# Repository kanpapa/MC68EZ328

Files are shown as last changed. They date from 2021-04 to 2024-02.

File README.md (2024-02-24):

# MC68EZ328 DragonOne SBC

We are designing the MC68EZ328 DragonOne SBC with KiCad.

Based on DragonOne V1.0 (C) Khaled Hassounah  
http://www.mediumware.net/DragonOne/DragonOne.htm  

## Spec

* CPU: MC68EZ328 DragonBall-EZ
* Flash Memory: Am29LV033C 32 Megabit (4M x 8-Bit) x 2
* DRAM: MT4LC4M16R6 64 Megabit (4M x 16-bit)
* RTC: DS1306

## Repository Contents

* /b/
  * All b-record for programming and testing the MC68EZ328 DragonOne.
* /bbug/
  * BBUG: a bootstrap mode debugger. Implementation of BBUG using python3 and pyserial.
* /d/
  * This is the data to execute a series of commands in 68k-Monitor.  
* /Hardware/
  * PDF files of schematics and BOMs
* /KiCad/
  * PCB design data and Gerber data for [KiCad](https://www.kicad.org/).
* /Pictues/
  * some pictures
* /src
  * All Source Code for Flash Programming and test programming. The assembler uses [EASy68K](http://www.easy68k.com/).

## How to install uClinux for the DragonOne SBC

[How to install uClinux](/uClinux-build2flash_en.md)  

See below for the uClinux source code and tools for the MC68EZ328 DragonOne SBC.  
https://github.com/kanpapa/uClinux-dist-20020220  
https://github.com/kanpapa/m68k-elf-tools  

## Blog

You can also refer to my blog. (in Japanese)    
https://kanpapa.com/today/electronics/microcomputer/mc68ez328/

## Pictures

MC68EZ328 CPU  
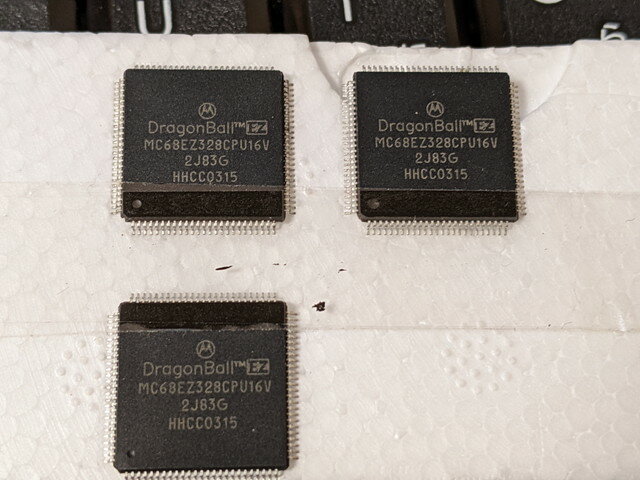
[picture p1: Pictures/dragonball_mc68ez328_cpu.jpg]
MC68EZ328 CPU


CPU board Rev. 0.3 PCB image  
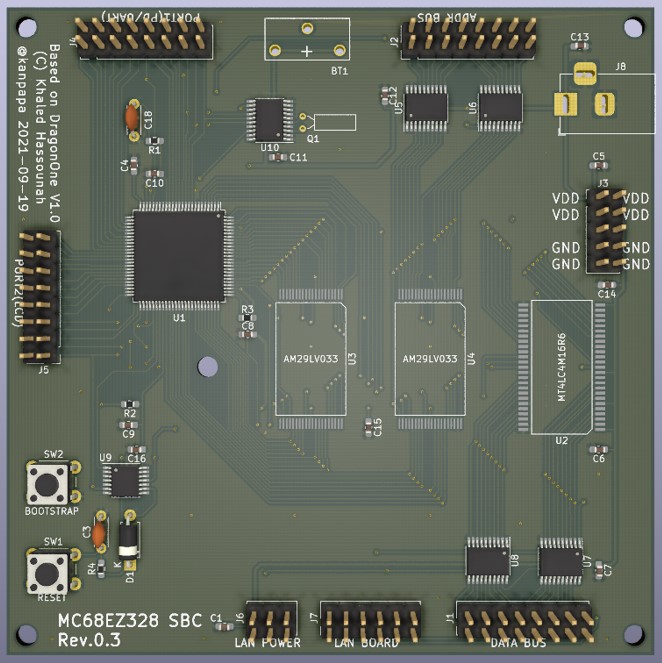
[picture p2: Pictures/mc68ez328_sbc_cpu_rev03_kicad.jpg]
CPU PCB image by KiCad


LAN board Rev. 0.2 PCB image  
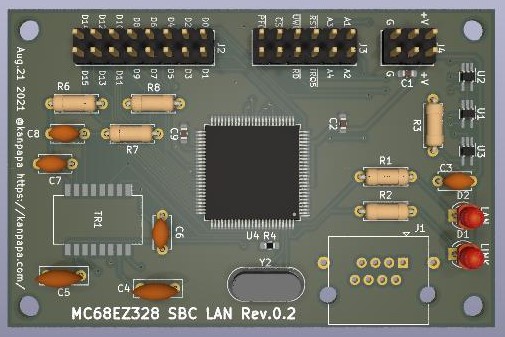
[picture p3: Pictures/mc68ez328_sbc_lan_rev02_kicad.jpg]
LAN PCB image by KiCad


Running uClinux  
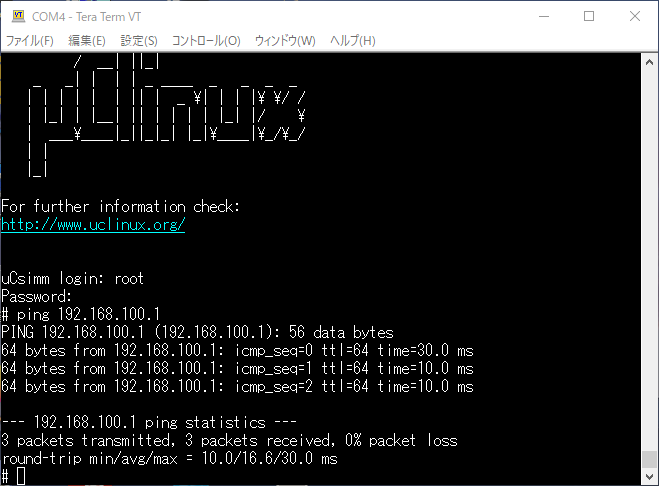
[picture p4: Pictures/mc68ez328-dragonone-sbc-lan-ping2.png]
Running uClinux


Running Network!  
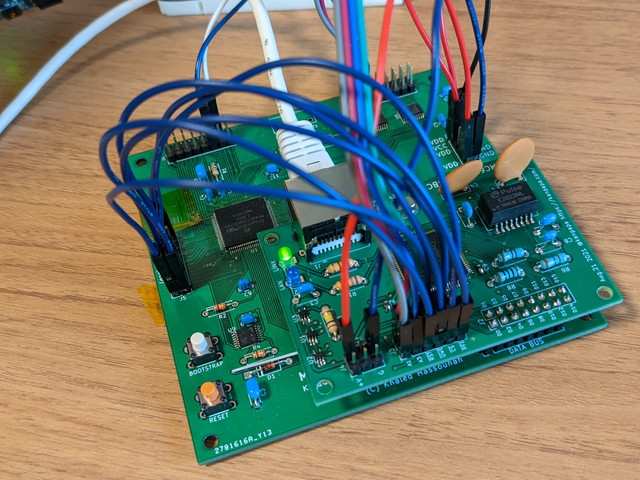
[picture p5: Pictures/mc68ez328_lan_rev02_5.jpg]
Running Network


## License Information

This code is public domain under the BSD-3-Clause License.  
Copyright (c) 2021, Kazuhiro Ouchi  
All rights reserved.  

References to any products, programs or services do not imply that they will be available in all countries in which their respective owner operates.

Company, product, or services names may be trademarks or services marks of others.

All libraries used in this code are copyright their respective authors.

68k-Monitor Copyright (c) 2015, Hayden Kroepfl

The DragonOne Microcomputer hardware design Copyright (C) Khaled Hassounah

Many thanks to the original authors for making their designs and code avaialble as open source.

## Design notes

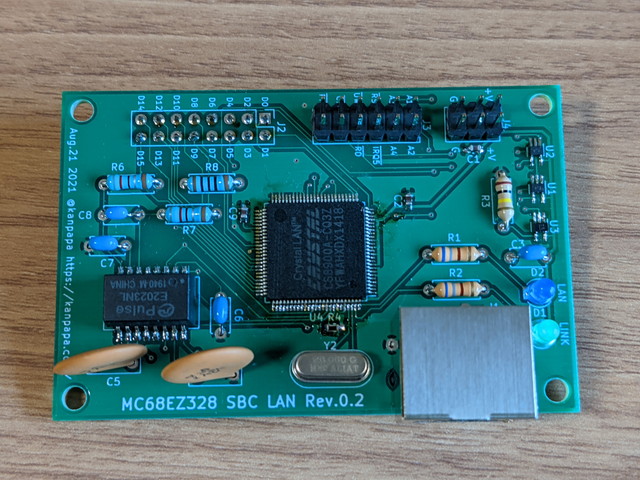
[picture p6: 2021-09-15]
Pictures/mc68ez328_lan_rev02_3.jpg

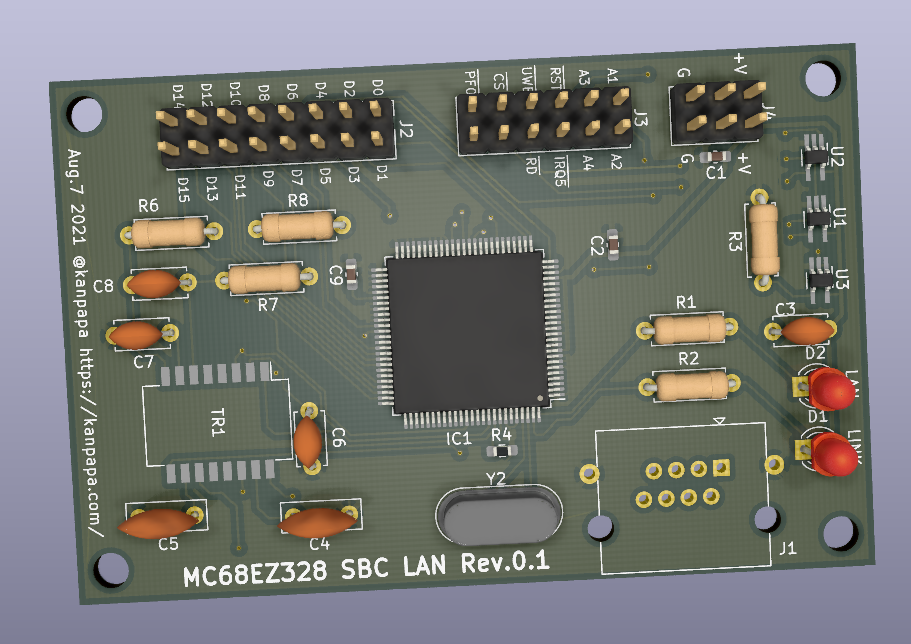
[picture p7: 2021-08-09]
Pictures/mc68ez328_sbc_lan_rev01_kicad.png

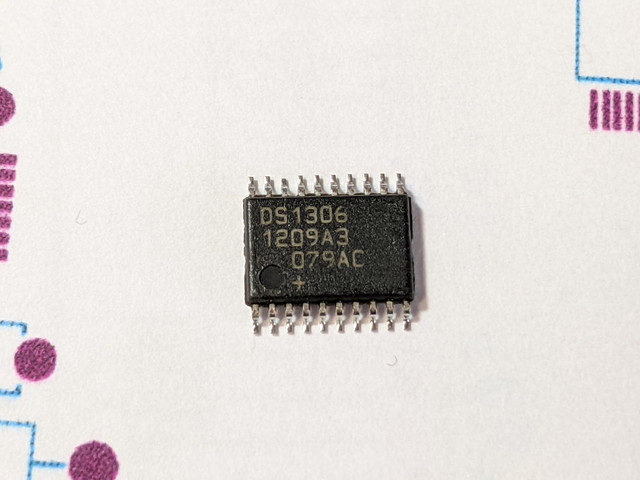
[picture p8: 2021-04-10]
Pictures/dragonone_ds1306.jpg

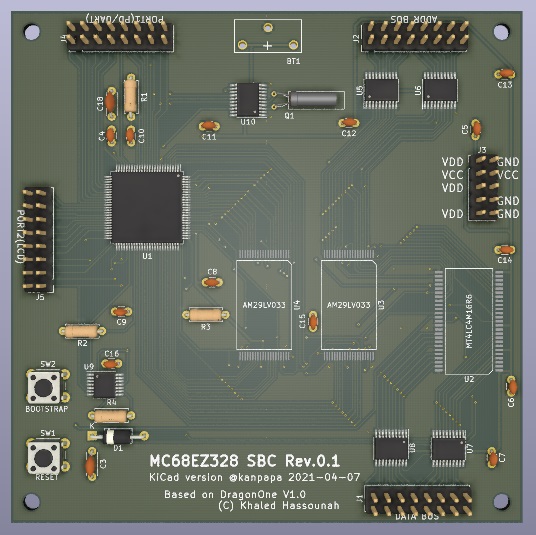
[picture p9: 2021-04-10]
Pictures/DragonOne_rev01_kicad.jpg

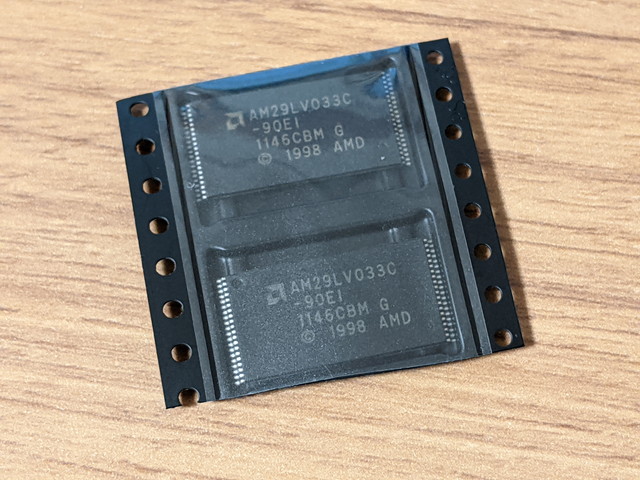
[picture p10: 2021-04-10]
Pictures/dragonone_am29lv033c.jpg

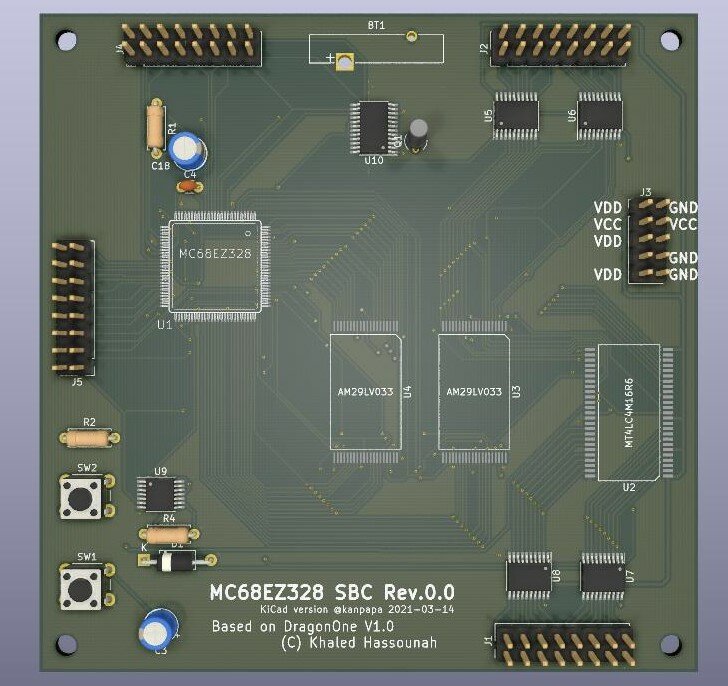
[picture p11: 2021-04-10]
Pictures/DragonOne_rev00_kicad.jpg

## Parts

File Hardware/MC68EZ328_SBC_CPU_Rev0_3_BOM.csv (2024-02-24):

Reference | Quantity | Value | Footprint | 販売店（参考） | 型番 | URL | 備考
BT1 | 1 | 3V | DragonOne_rev00:CH74-2032LF | 秋月電子 | ボタン電池基板取付用ホルダーＣＲ２０３２用（縦・小型）[CH74-2032LF][P-01443]1個 ￥50(税込) | https://akizukidenshi.com/catalog/g/gP-01443/
C3 C18 | 2 | 2.2uf | Capacitor_THT:C_Disc_D4.3mm_W1.9mm_P5.00mm | 秋月電子 | 積層セラミックコンデンサー２．２μＦ５０Ｖ Ｘ７Ｒ ５ｍｍ[RDER71H225K2K1H03B][P-08152]1個 ￥25(税込) | https://akizukidenshi.com/catalog/g/gP-08152/
C1 C4 C5 C6 C7 C8 C9 C10 C11 C12 C13 C14 C15 C16 | 14 | 0.1uf | Capacitor_SMD:C_0603_1608Metric_Pad1.08x0.95mm_HandSolder | 秋月電子 | 太陽誘電チップ積層セラミックコンデンサー０．１μＦ２５Ｖ Ｆ／Ｙ５Ｖ １６０８ （１００個入）[TMK107F104ZZ-T][P-13071]1パック ￥100 | https://www.akizukidenshi.com/catalog/g/gP-13071/
D1 | 1 | 1N4148 | Diode_THT:D_A-405_P10.16mm_Horizontal | 秋月電子 | 汎用小信号高速スイッチング・ダイオード１Ｎ４１４８ １００Ｖ２００ｍＡ（５０本入）[1N4148][I-00941]1パック ￥100(税込) | https://akizukidenshi.com/catalog/g/gI-00941/
J1 | 1 | DATA_BUS | Connector_PinHeader_2.54mm:PinHeader_2x08_P2.54mm_Vertical | 秋月電子 | ピンヘッダ２×８ | https://akizukidenshi.com/catalog/g/gC-00082/ | ピンヘッダ２×４０（８０Ｐ）[PH-2x40SG][C-00082]1本￥50(税込)を折って使う
J2 | 1 | ADDR_BUS | Connector_PinHeader_2.54mm:PinHeader_2x08_P2.54mm_Vertical | 秋月電子 | ピンヘッダ２×８
J3 | 1 | POWER | Connector_PinHeader_2.54mm:PinHeader_2x05_P2.54mm_Vertical | 秋月電子 | ピンヘッダ２×５
J4 | 1 | PORT1 | Connector_PinHeader_2.54mm:PinHeader_2x08_P2.54mm_Vertical | 秋月電子 | ピンヘッダ２×８
J5 | 1 | PORT2 | Connector_PinHeader_2.54mm:PinHeader_2x08_P2.54mm_Vertical | 秋月電子 | ピンヘッダ２×８
J6 | 1 | LAN POWER | Connector_PinHeader_2.54mm:PinHeader_2x03_P2.54mm_Vertical | 秋月電子 | ピンヘッダ２×３
J7 | 1 | LAN BOARD | Connector_PinHeader_2.54mm:PinHeader_2x06_P2.54mm_Vertical | 秋月電子 | ピンヘッダ２×６
J8 | 1 | POWER | Cobbector_BarrelJack:BarrelJack_Horizontal | 秋月電子 | ２．１ｍｍ標準ＤＣジャック基板取付用 ＭＪ－１７９Ｐ[MJ-179P][C-00077]1個 ￥40(税込) | https://www.akizukidenshi.com/catalog/g/gC-00077/
Q1 | 1 | 32.768kHz | Crystal:Crystal_AT310_D3.0mm_L10.0mm_Horizontal | 秋月電子 | クリスタル（水晶発振子）32.768KHz[VT-200-F 32.768kHz][P-04005]1個 ￥30(税込) | https://akizukidenshi.com/catalog/g/gP-04005/
R1 | 1 | 430Ω | Resistor_SMD:R_0603_1608Metric_Pad0.98x0.95mm_HandSolder | 千石電商日米商事共立エレショップ | チップ抵抗１／１０Ｗ４３０Ω ０６０３ １６０８
R2 R3 R4 | 3 | 3.3K | Resistor_SMD:R_0603_1608Metric_Pad0.98x0.95mm_HandSolder | 千石電商日米商事秋月電子共立エレショップ | チップ抵抗１／１０Ｗ３．３ｋΩ ０６０３ １６０８ | https://www.akizukidenshi.com/catalog/g/gR-14661/
SW1 | 1 | RESET | Button_Switch_THT:SW_PUSH_6mm | 秋月電子 | タクトスイッチ（オレンジ色）[TS-0606-F-N-ORG][P-03652]1個 ￥10(税込) | https://akizukidenshi.com/catalog/g/gP-03652/
SW2 | 1 | BOOTSTRAP | Button_Switch_THT:SW_PUSH_6mm | 秋月電子 | タクトスイッチ（白色）[TS-0606-F-N-WHT][P-03648]1個 ￥10(税込) | https://akizukidenshi.com/catalog/g/gP-03648/ | 色はおこのみで
U1 | 1 | MC68EZ328 | Package_QFP:TQFP-100_14x14mm_P0.5mm | AliExpress、eBay
U10 | 1 | DS1306 | Package_SO:TSSOP-20_4.4x6.5mm_P0.65mm | AliExpress、eBay
U2 | 1 | MT4LC4M16R6 | DragonOne_rev00:TSOP-II-50_21x10.16mm_P0.8mm | AliExpress、eBay
U3 U4 | 2 | AM29LV033 | DragonOne_rev00:TSOP-I-40_18.4x10mm_P0.5mm | AliExpress、eBay
U5 U6 U7 U8 | 4 | 74LCX245 | Package_SO:TSSOP-20_4.4x6.5mm_P0.65mm | 秋月電子 | ８ビットバストランシーバ３ステート出力７４ＬＣＸ２４５ＦＴ（５個入）[74LCX245FT(AJ)][I-14111]1パック ￥130(税込) | https://akizukidenshi.com/catalog/g/gI-14111/
U9 | 1 | 74LCX00 | Package_SO:TSSOP-14_4.4x5mm_P0.65mm | 秋月電子 | ４回路２入力ＮＡＮＤ７４ＬＣＸ００ＦＴ（５個入）[74LCX00FT(AJ)][I-14106]1パック ￥100(税込) | https://akizukidenshi.com/catalog/g/gI-14106/

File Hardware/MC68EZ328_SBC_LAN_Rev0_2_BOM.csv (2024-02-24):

Reference | Quantity | Value | 販売店（参考） | 型番 | URL | 備考
C1 C2 C9 | 3 | 0.1uF | 秋月電子 | 太陽誘電チップ積層セラミックコンデンサー０．１μＦ２５Ｖ Ｆ／Ｙ５Ｖ １６０８ （１００個入）[TMK107F104ZZ-T][P-13071]1パック ￥100(税込) | https://akizukidenshi.com/catalog/g/gP-13071/
C4 C5 | 2 | 4700pF/1kV | マルツ | セラミックコンデンサー 4700pF【CY5P472K1K12D】パッケージ：・静電容量：4700pF・定格電圧：1kVDC・容量許容差：±10％・リードピッチ：5mm | https://www.marutsu.co.jp/GoodsDetail.jsp?q=CY5P472K&salesGoodsCode=226316
C3 C6 C7 | 3 | 0.1uF | 秋月電子 | リード型積層セラミックコンデンサー０．１μＦ５０Ｖ Ｆ ５ｍｍピッチ （１０個入）[RPEF11H104Z2M1A01A][P-00340]1テープ ￥100(税込) | https://akizukidenshi.com/catalog/g/gP-00340/
C8 | 1 | 560pF | 秋月電子 | 絶縁ラジアルリード型積層セラミックコンデンサー５６０ｐＦ５０Ｖ５ｍｍ（１０個入）[RDE5C1H561J0K1H03B][P-08111]1パック ￥100(税込) | https://akizukidenshi.com/catalog/g/gP-08111/
D1 | 1 | LINK LED | aitendo
D2 | 1 | LAN LED | aitendo
IC1 | 1 | CS8900A-CQ3Z | AliExpress
J1 | 1 | LAN_CON | 秋月電子 | 基板取付用ＬＡＮコネクタ（モジュラージャック）（ＲＪ－４５）[7810-8P8C][C-00159]1個 ￥100(税込) | https://akizukidenshi.com/catalog/g/gC-00159/
J2 | 1 | DATA_BUS | 秋月電子 | ピンヘッダ２×４０（８０Ｐ）[PH-2x40SG][C-00082]1本 ￥50(税込) | https://akizukidenshi.com/catalog/g/gC-00082/ | 折って使う
J3 | 1 | CTRL_BUS | 秋月電子 | ピンヘッダ２×４０（８０Ｐ）[PH-2x40SG][C-00082]1本 ￥50(税込) | https://akizukidenshi.com/catalog/g/gC-00082/ | 折って使う
J4 | 1 | PWR | 秋月電子 | ピンヘッダ２×３（６Ｐ）[PH-2x3SG][C-15825]1本 ￥10(税込) 数割有 | https://akizukidenshi.com/catalog/g/gC-15825/
R1 R2 | 2 | 560Ω | 千石電商 | カーボン抵抗 1/4W 560Ω±5% RD25J 560Ω
R3 | 1 | 100K | 千石電商 | カーボン抵抗 1/4W 100KΩ±5% RD25J 100KΩ
R4 | 1 | 4.99K 1% | 秋月電子 | 超精密級 金属皮膜チップ抵抗器 １６０８ １／１０Ｗ４．９９ｋΩ０．１％（５個入）[RG1608N-4991B-T5][R-11794]1パック ￥100(税込) | https://akizukidenshi.com/catalog/g/gR-11794/
R6 R7 | 2 | 8.2 1% | 千石電商 | 金属被膜抵抗器 1/4W 8.2Ω±1% RLC25FX 8.2Ω
R8 | 1 | 100, 1% | 千石電商 | 金属被膜抵抗器 1/4W 100Ω±1% RLC25FY 100Ω
TR1 | 1 | E2023EL | マルツ, AliExpress
U1 U2 | 2 | TC7S32FU | 秋月電子 | ２入力ＯＲゲートＴＣ７Ｓ３２ＦＵ（５個入）[TC7S32FU][I-10465]1パック ￥150(税込) | https://akizukidenshi.com/catalog/g/gI-10465/
U3 | 1 | TC7SH00FU | 秋月電子 | ２入力ＮＡＮＤ ＴＣ７ＳＨ００ＦＵ（１０個入）[TC7SH00FULJ(CB][I-15748]1パック ￥100(税込) | https://akizukidenshi.com/catalog/g/gI-15748/
Y2 | 1 | 20MHz | 秋月電子 | クリスタル（水晶発振子）２０ＭＨｚ[HUSG-20.000-20][P-08673]1個 ￥30(税込) | https://akizukidenshi.com/catalog/g/gP-08673/

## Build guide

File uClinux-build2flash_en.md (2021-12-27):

# How to install the uClinux for the DragonOne SBC

## Installing the OS in the build environment

Run debian i386 in a VMWare Player virtual environment.

1. Install VMware Workstation Player. (Free for non-commercial use).
1. Download [debian-11.2.0-i386-netinst.iso](https://cdimage.debian.org/debian-cd/current/i386/iso-cd/) from [debian official site](https://www.debian.org/).
1. Create a new virtual machine and run debian 11.x 32bit.

## Install the necessary packages.

After debian i386 is started, follow the steps below to install the necessary packages.

```
$ sudo apt install build-essential
$ sudo apt install git
$ sudo apt install wish
```

## Download the resources needed for the build from GitHub.com

~/git as the working environment.

```
$ mkdir git
$ cd git
$ git clone https://github.com/kanpapa/uClinux-dist-20020220.git
$ git clone https://github.com/kanpapa/m68k-elf-tools.git
$ git clone https://github.com/kanpapa/MC68EZ328.git
```

## Installing the 68000 toolchain

```
$ cd ~/git/m68k-elf-tools
$ sudo ./m68k-elf-tools-20030314.sh
```

The 68000 toolchain will be installed under /usr/local.

## Building uClinux

```
$ cd ~/git/uClinux-dist-20020220/uClinux-dist
$ make xconfig
$ make dep
$ make
```

In xconfig, the target should be set as follows.

```
Lineo/uCsimm    Vender/Product
uClinux-2.4.x   Kernel Version
uC-libc         LibC Version
```

If the build is successful, uClinux-dist/images/image.bin will be generated.

## Create a bootstrap file

Add the image.bin converted to a b-record to the b-record of the monitor with the flash writing function, and finally add a b-record to start the monitor.

```
$ cd ~/git/MC68EZ328/bbug
$ python3 bin2b.py ~/git/uClinux-dist-20020220/uClinux-dist/images/image.bin > ../b/image.b
$ cd ../b
$ cat Monitor_flashtool_dram_nostart.b image.b > upload.b
$ echo "0000100000" >> upload.b
```

## Writing to flash memory

1. Set the MC68EZ328 SBC to bootstrap mode.
    * While holding down the BOOTSTRAP switch, press the RESET switch.
    * Press the Enter key once and make sure "@" is displayed.
1. Upload upload.b from the serial terminal.
    * If you use Teraterm, add a delay. (0ms for each character, about 100ms for each new line)
1. When the upload is complete, the monitor with flash writing function will start.
    ```
    Passed.
    
    Chartreuse's 68000 RAM Monitor
    for MC68EZ328 + Flashtool by kanpapa
    ==============================
    Available Commands: 
     (E)xamine   (D)eposit     (G)o      (H)elp
    Flash Commands: 
     (I)nfo      (F)lash Erase (P)rogram (R)eset
    >
    ````
1. Dump and confirm that the contents of image.b are loaded into 0x00200000.
    ```
    > E 00200000+10
    00200000: 00 7F FF FC 10 00 04 01 10 00 23 5C 10 00 23 78 ..........#\..#x
    ```
1. Erases the flash memory.
    ```
    > F
    Sending chip erase command sequence
    ...................................
         :
    ..................................
    lower chip DQ5 is up
    
    upper chip DQ5 is up
    
    Erase Successful.
    >
    ```
1. Write to flash memory.
    ```
    > P
    Programming
    
    Source address: 00200000
    Dest address: 10000000
    Length: 00200000
    10000000
    10001000
        :
    10200000
    Success
    >
    ```

## Checking uClinux startup

Press the reset button to start uClinux with MC68EZ328 SBC.

```
Linux version 2.4.17-uc0 (ocha@debian) (gcc version 2.95.3 20010315 (release)(ColdFire patches - 20010318 from http://fiddes.net/coldfire/)(uClinux XIP and shared lib patches from http://www.snapgear.com/)) #3 Sun 22 Aug 2021 04:05:22 PM JST

68EZ328 DragonBallEZ support (C) 1999 Rt-Control, Inc

uClinux/MC68EZ328
Flat model support (C) 1998,1999 Kenneth Albanowski, D. Jeff Dionne
On node 0 totalpages: 2048
zone(0): 0 pages.
zone(1): 2048 pages.
zone(2): 0 pages.
Kernel command line:
Calibrating delay loop... 0.92 BogoMIPS
Memory available: 7692k/8064k RAM, 0k/0k ROM (570k kernel code, 225k data)
Dentry-cache hash table entries: 1024 (order: 1, 8192 bytes)
Inode-cache hash table entries: 512 (order: 0, 4096 bytes)
Mount-cache hash table entries: 512 (order: 0, 4096 bytes)
Buffer-cache hash table entries: 1024 (order: 0, 4096 bytes)
Page-cache hash table entries: 2048 (order: 1, 8192 bytes)
POSIX conformance testing by UNIFIX
Linux NET4.0 for Linux 2.4
Based upon Swansea University Computer Society NET3.039
Initializing RT netlink socket
Starting kswapd
MC68328 serial driver version 1.00
ttyS0 at 0xfffff900 (irq = 64) is a builtin MC68328 UART
block: 64 slots per queue, batch=16
RAMDISK driver initialized: 16 RAM disks of 4096K size 1024 blocksize
cs89x0:cs89x0_probe(0x0)
cs89x0: Setting up uCsimm CS8900 Chip Select & IRQ ioaddr = 0x2000300
cs89x0.c: v2.4.3-pre1 Russell Nelson <nelson@crynwr.com>, Andrew Morton <andrewm@uow.edu.au>
eth0: cs8900 rev K found at 0x2000300
cs89x0 media RJ-45, IRQ 20, programmed I/O, MAC 00:10:8b:f1:da:01
cs89x0_probe1() successful
Blkmem copyright 1998,1999 D. Jeff Dionne
Blkmem copyright 1998 Kenneth Albanowski
Blkmem 1 disk images:
0: 100B4FB8-101847B7 [VIRTUAL 100B4FB8-101847B7] (RO)
NET4: Linux TCP/IP 1.0 for NET4.0
IP Protocols: ICMP, UDP, TCP
IP: routing cache hash table of 512 buckets, 4Kbytes
TCP: Hash tables configured (established 512 bind 512)
NET4: Unix domain sockets 1.0/SMP for Linux NET4.0.
VFS: Mounted root (romfs filesystem) readonly.
eth0: using half-duplex 10Base-T (RJ-45)
Welcome to
          ____ _  _
         /  __| ||_|
    _   _| |  | | _ ____  _   _  _  _
   | | | | |  | || |  _ \| | | |\ \/ /
   | |_| | |__| || | | | | |_| |/    \
   |  ___\____|_||_|_| |_|\____|\_/\_/
   | |
   |_|

For further information check:
http://www.uclinux.org/

uCsimm login: root
Password:
#
```

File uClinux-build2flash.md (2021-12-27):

# uClinuxのビルドからフラッシュへの書き込みまで

## ビルド環境のOSのインストール

debian i386をVMWare Playerの仮想環境で動かします。

1. VMware Workstation Playerをインストールします。(非営利目的であれば無償)
1. [debian](https://www.debian.org/)の公式サイトから[debian-11.2.0-i386-netinst.iso](https://cdimage.debian.org/debian-cd/current/i386/iso-cd/)をダウンロードします。
1. 新規仮想マシンの作成で、debian 11.x 32bitを動かします。

## 必要なパッケージをインストール

debian i386が起動したら以下の手順で必要なパッケージをインストールします。

```
$ sudo apt install build-essential
$ sudo apt install git
$ sudo apt install wish
```

## ソースをGitHub.comからダウンロード

~/gitを作業環境としています。

```
$ mkdir git
$ cd git
$ git clone https://github.com/kanpapa/uClinux-dist-20020220.git
$ git clone https://github.com/kanpapa/m68k-elf-tools.git
$ git clone https://github.com/kanpapa/MC68EZ328.git
```

## 68000のツールチェインのインストール

```
$ cd ~/git/m68k-elf-tools
$ sudo ./m68k-elf-tools-20030314.sh
```

/usr/local 配下に68000のツールチェインがインストールされます。

## uClinuxのビルド

```
$ cd ~/git/uClinux-dist-20020220/uClinux-dist
$ make xconfig
$ make dep
$ make
```

xconfigでターゲットは以下のように設定します。

```
Lineo/uCsimm    Vender/Product
uClinux-2.4.x   Kernel Version
uC-libc         LibC Version
```

ビルドが成功すれば、uClinux-dist/images/image.bin が生成されます。

## ブートストラップファイルの作成

フラッシュ書き込み機能付きモニタのbレコードに、bレコードに変換したimage.binを追加し、最後にモニタを起動するbレコードを追加します。

```
$ cd ~/git/MC68EZ328/bbug
$ python3 bin2b.py ~/git/uClinux-dist-20020220/uClinux-dist/images/image.bin > ../b/image.b
$ cd ../b
$ cat Monitor_flashtool_dram_nostart.b image.b > upload.b
$ echo "0000100000" >> upload.b
```

## フラッシュメモリへの書き込み

1. MC68EZ328 SBCをブートストラップモードにします。
    * BOOTSTRAPスイッチを押したまま、RESETスイッチを押します。
    * Enterキーを一度押し、"@"が表示されることを確認します。
1. upload.bをシリアルターミナルからアップロードします。
    * Teratermを使う場合は、遅延を入れます。(1文字ごとに0ms, 改行ごとに100ms程度）
1. アップロードが完了すると、フラッシュ書き込み機能付きモニタが起動します。
    ```
    Passed.
    
    Chartreuse's 68000 RAM Monitor
    for MC68EZ328 + Flashtool by kanpapa
    ==============================
    Available Commands: 
     (E)xamine   (D)eposit     (G)o      (H)elp
    Flash Commands: 
     (I)nfo      (F)lash Erase (P)rogram (R)eset
    >
    ````
1. image.bの内容が0x00200000に読み込まれていることをダンプして確認します。
    ```
    > E 00200000+10
    00200000: 00 7F FF FC 10 00 04 01 10 00 23 5C 10 00 23 78 ..........#\..#x
    ```
1. フラッシュメモリを消去します。
    ```
    > F
    Sending chip erase command sequence
    ...................................
         :
    ..................................
    lower chip DQ5 is up
    
    upper chip DQ5 is up
    
    Erase Successful.
    >
    ```
1. フラッシュメモリに書き込みます。
    ```
    > P
    Programming
    
    Source address: 00200000
    Dest address: 10000000
    Length: 00200000
    10000000
    10001000
        :
    10200000
    Success
    >
    ```

## uClinuxの起動確認

リセットボタンを押すとMC68EZ328 SBCでuClinuxが起動します。

```
Linux version 2.4.17-uc0 (ocha@debian) (gcc version 2.95.3 20010315 (release)(ColdFire patches - 20010318 from http://fiddes.net/coldfire/)(uClinux XIP and shared lib patches from http://www.snapgear.com/)) #3 Sun 22 Aug 2021 04:05:22 PM JST

68EZ328 DragonBallEZ support (C) 1999 Rt-Control, Inc

uClinux/MC68EZ328
Flat model support (C) 1998,1999 Kenneth Albanowski, D. Jeff Dionne
On node 0 totalpages: 2048
zone(0): 0 pages.
zone(1): 2048 pages.
zone(2): 0 pages.
Kernel command line:
Calibrating delay loop... 0.92 BogoMIPS
Memory available: 7692k/8064k RAM, 0k/0k ROM (570k kernel code, 225k data)
Dentry-cache hash table entries: 1024 (order: 1, 8192 bytes)
Inode-cache hash table entries: 512 (order: 0, 4096 bytes)
Mount-cache hash table entries: 512 (order: 0, 4096 bytes)
Buffer-cache hash table entries: 1024 (order: 0, 4096 bytes)
Page-cache hash table entries: 2048 (order: 1, 8192 bytes)
POSIX conformance testing by UNIFIX
Linux NET4.0 for Linux 2.4
Based upon Swansea University Computer Society NET3.039
Initializing RT netlink socket
Starting kswapd
MC68328 serial driver version 1.00
ttyS0 at 0xfffff900 (irq = 64) is a builtin MC68328 UART
block: 64 slots per queue, batch=16
RAMDISK driver initialized: 16 RAM disks of 4096K size 1024 blocksize
cs89x0:cs89x0_probe(0x0)
cs89x0: Setting up uCsimm CS8900 Chip Select & IRQ ioaddr = 0x2000300
cs89x0.c: v2.4.3-pre1 Russell Nelson <nelson@crynwr.com>, Andrew Morton <andrewm@uow.edu.au>
eth0: cs8900 rev K found at 0x2000300
cs89x0 media RJ-45, IRQ 20, programmed I/O, MAC 00:10:8b:f1:da:01
cs89x0_probe1() successful
Blkmem copyright 1998,1999 D. Jeff Dionne
Blkmem copyright 1998 Kenneth Albanowski
Blkmem 1 disk images:
0: 100B4FB8-101847B7 [VIRTUAL 100B4FB8-101847B7] (RO)
NET4: Linux TCP/IP 1.0 for NET4.0
IP Protocols: ICMP, UDP, TCP
IP: routing cache hash table of 512 buckets, 4Kbytes
TCP: Hash tables configured (established 512 bind 512)
NET4: Unix domain sockets 1.0/SMP for Linux NET4.0.
VFS: Mounted root (romfs filesystem) readonly.
eth0: using half-duplex 10Base-T (RJ-45)
Welcome to
          ____ _  _
         /  __| ||_|
    _   _| |  | | _ ____  _   _  _  _
   | | | | |  | || |  _ \| | | |\ \/ /
   | |_| | |__| || | | | | |_| |/    \
   |  ___\____|_||_|_| |_|\____|\_/\_/
   | |
   |_|

For further information check:
http://www.uclinux.org/

uCsimm login: root
Password:
#
```

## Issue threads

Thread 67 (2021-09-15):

Kicad files

fifteenhex, 2021-09-15:
Hi,

I would like to build one of these and see if I can get Linux 5.15 running on it.
Will you upload the kicad files soon?

Thanks,

Daniel

kanpapa, 2021-09-15:
Hi, Daniel

Thank you for your interest in this project.
We are currently designing Rev.0.3, which allows network boards to be connected.

https://github.com/kanpapa/MC68EZ328/blob/main/Pictures/dragonone_rev03_2021-09-16_063345.png

We are planning to release the KiCad file when this design is completed.
Please wait a little longer.

You can also refer to my blog.
https://kanpapa.com/today/electronics/microcomputer/mc68ez328/

Regards,

Kazu

kanpapa, 2021-09-20:
I pushed the KiCad file to the kanpapa-patch-1 branch.
The PCB is now being manufactured using this data.
I will merge it into main once I have confirmed that it works with this PCB.

fifteenhex, 2021-09-20:
> I pushed the KiCad file to the kanpapa-patch-1 branch.
> The PCB is now being manufactured using this data.
> I will merge it into main once I have confirmed that it works with this PCB.

Awesome. Thank you!

kanpapa, 2021-09-27:
#76 The board was fabricated using this KiCad data and it worked.

Closed 2021-09-27.

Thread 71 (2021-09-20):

Power-on reset does not work.

kanpapa, 2021-09-20:

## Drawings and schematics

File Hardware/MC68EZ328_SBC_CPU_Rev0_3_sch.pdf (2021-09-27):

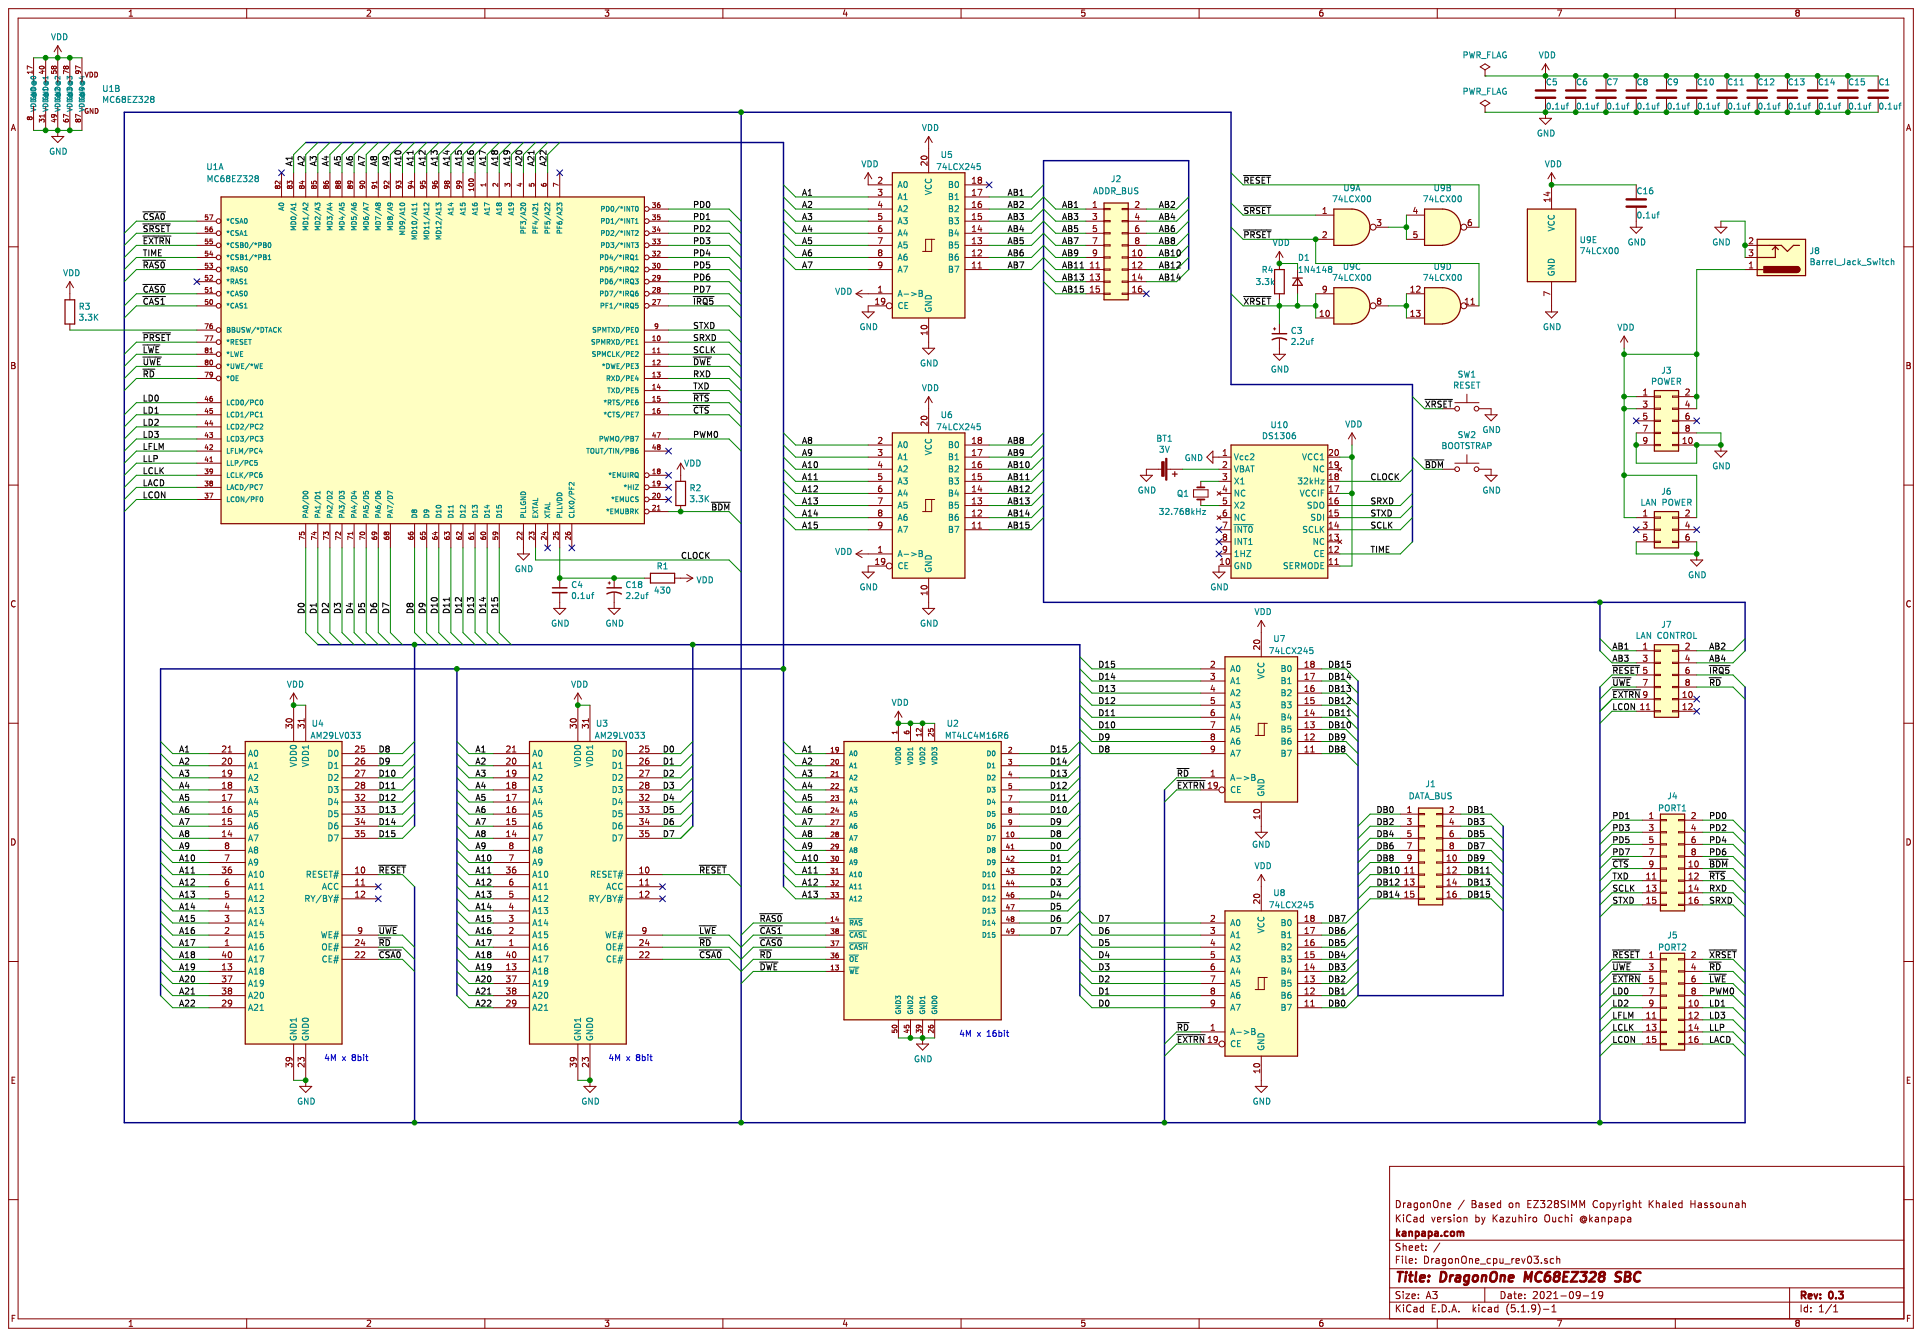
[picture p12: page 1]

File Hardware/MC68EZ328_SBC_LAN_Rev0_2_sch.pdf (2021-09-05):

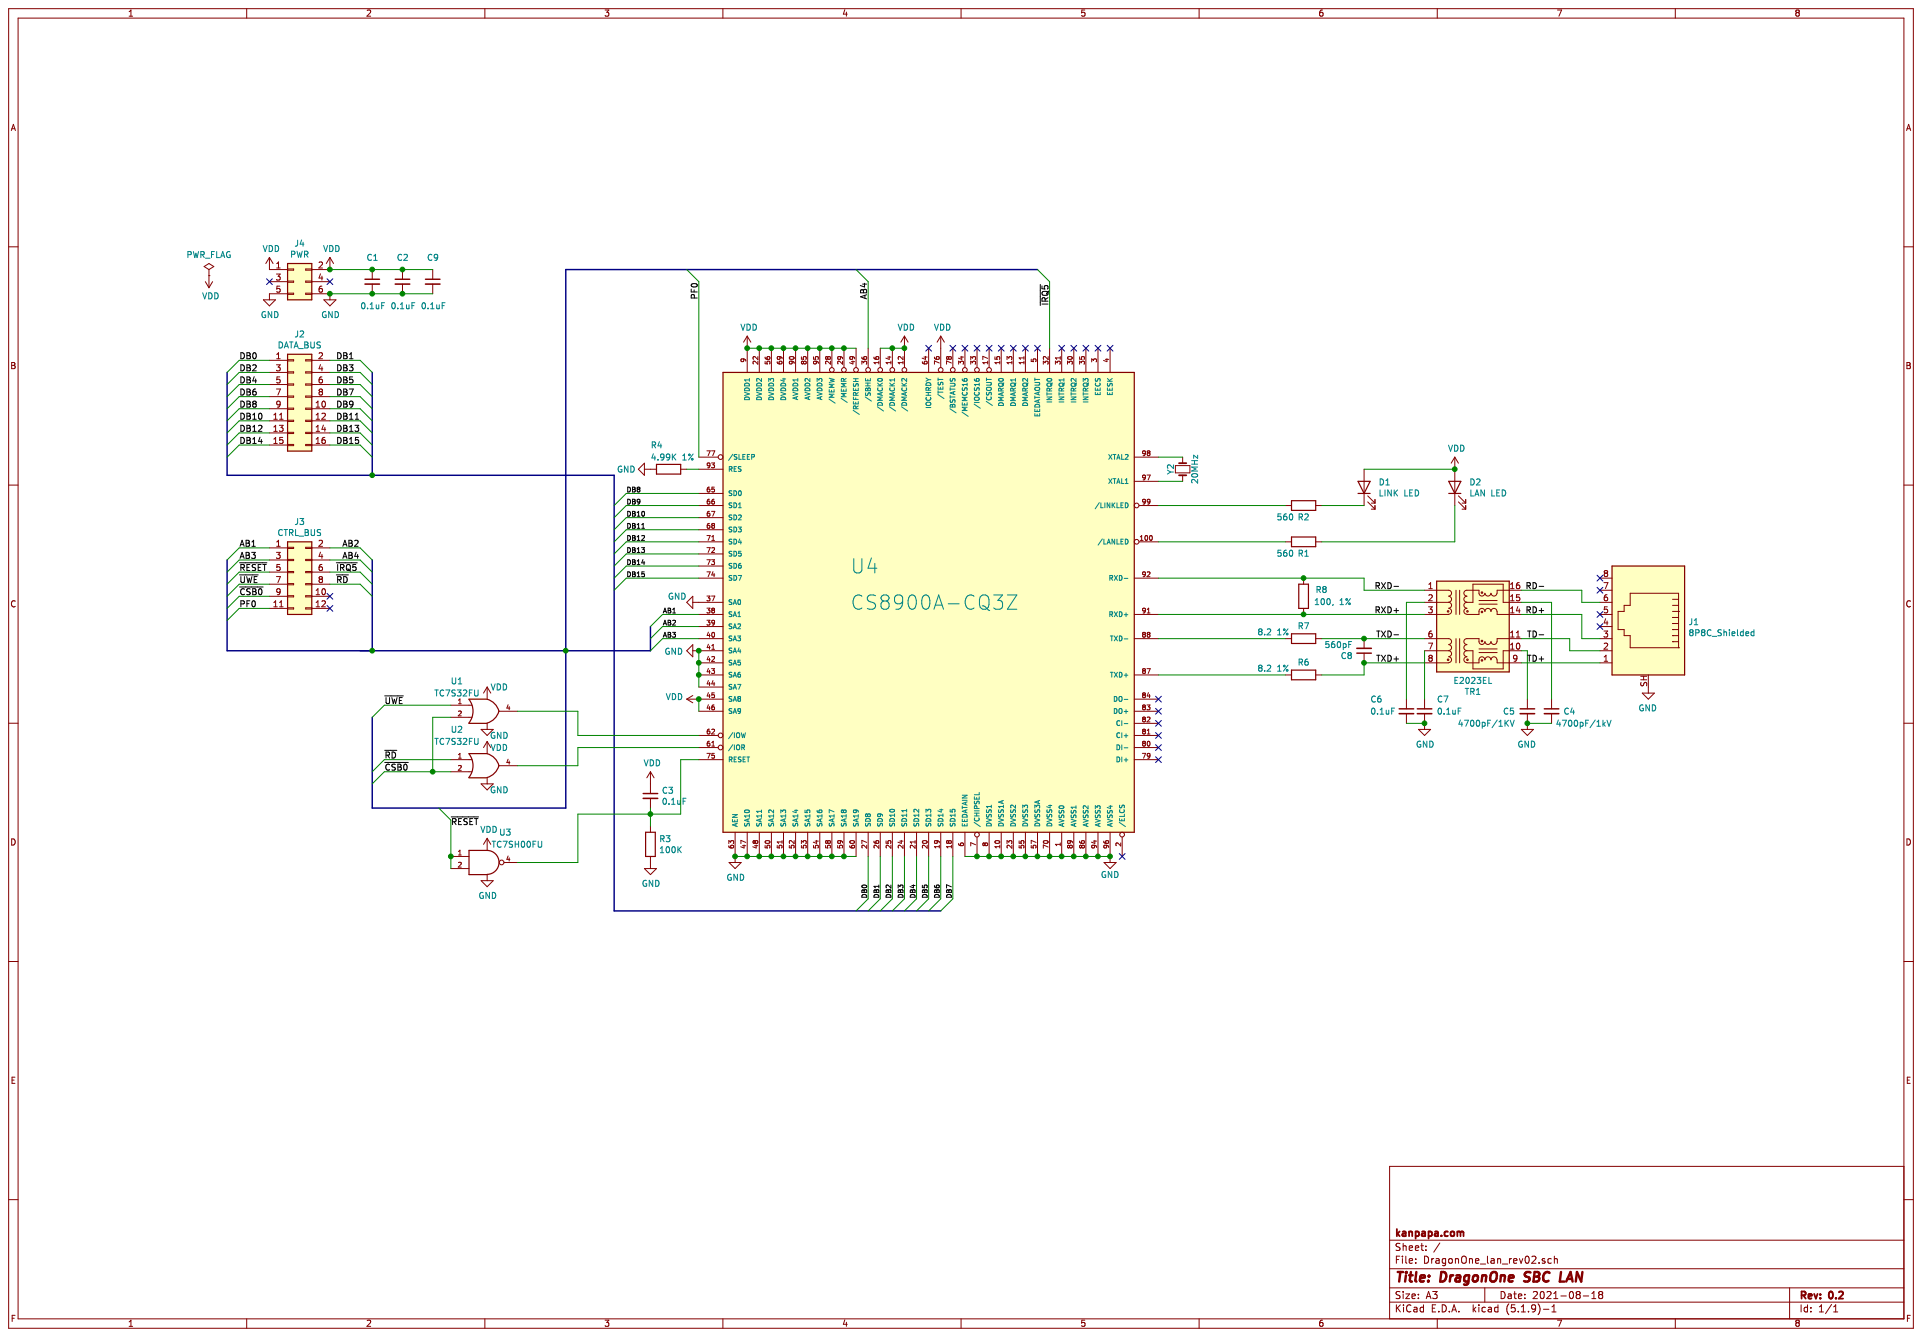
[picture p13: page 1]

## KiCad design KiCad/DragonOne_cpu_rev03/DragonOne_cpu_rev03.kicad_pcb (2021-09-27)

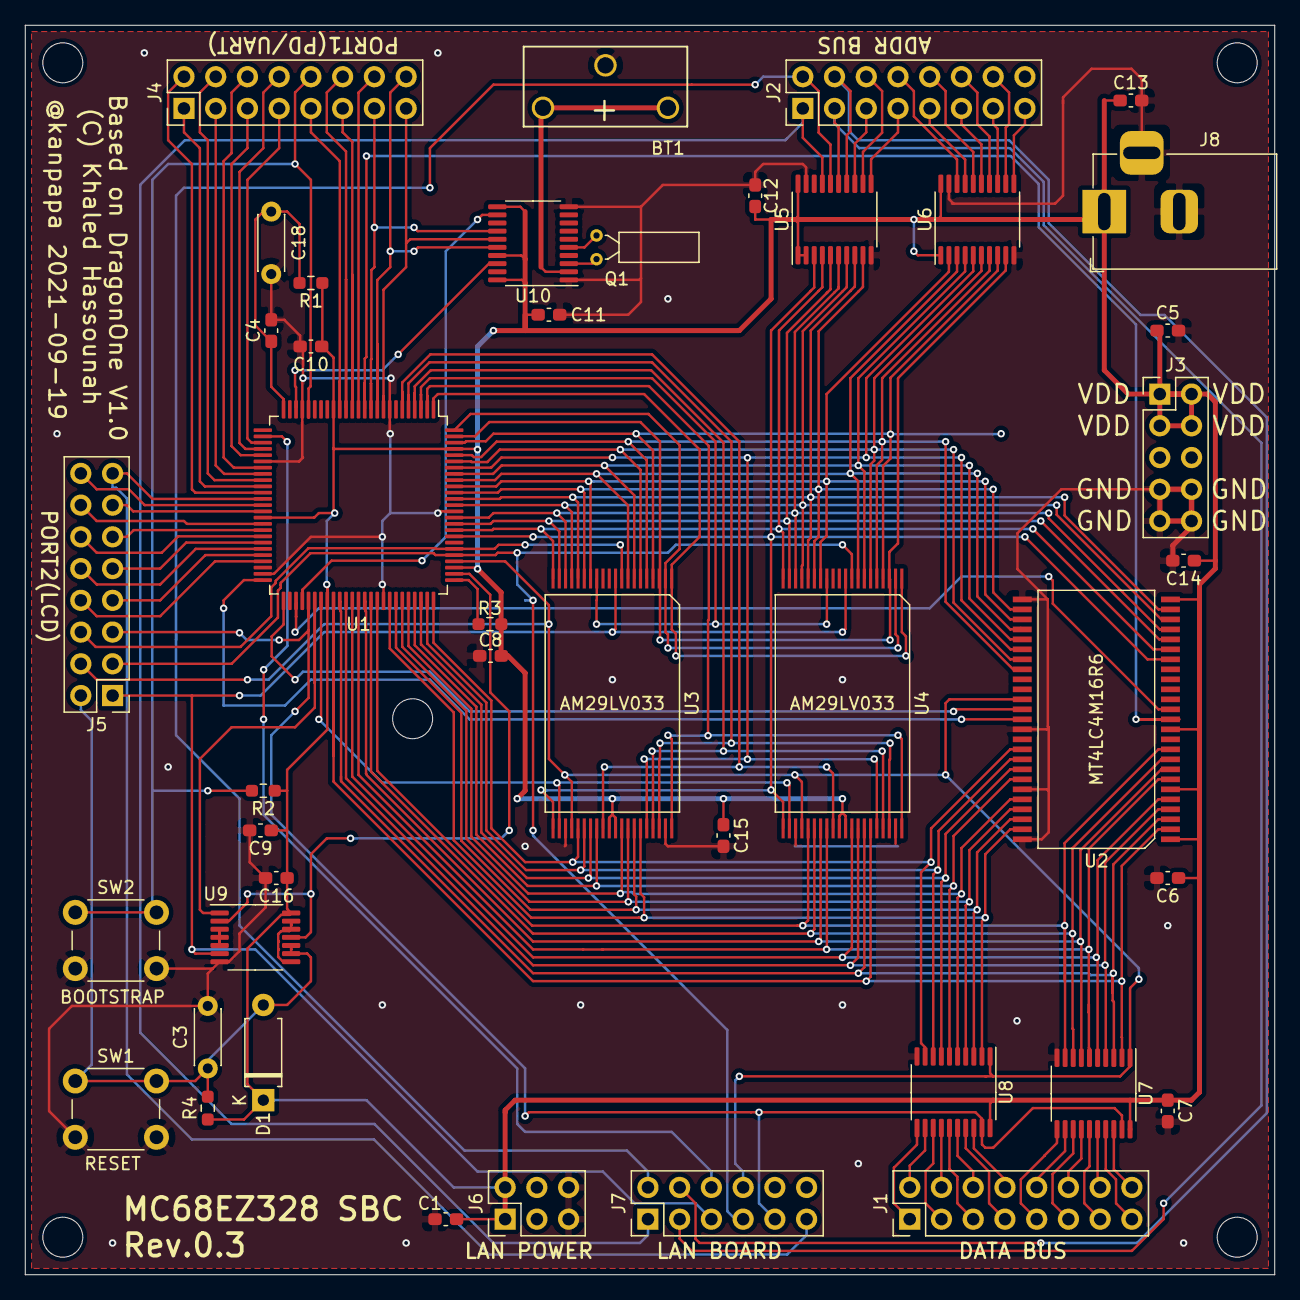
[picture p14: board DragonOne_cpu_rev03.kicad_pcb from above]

Board: 2 copper layers, 100.0 x 100.0 mm, 48 parts (0 on the bottom side), 120 nets.

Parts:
BT1: 3V; CH74-2032LF
C1, C4, C5, C6, C7, C8, C9, C10, C11, C12, C13, C14, C15, C16: 0.1uf; C_0603_1608Metric_Pad1.08x0.95mm_HandSolder
C3, C18: 2.2uf; C_Disc_D4.3mm_W1.9mm_P5.00mm
D1: 1N4148; D_A-405_P7.62mm_Horizontal
J1: DATA_BUS; PinHeader_2x08_P2.54mm_Vertical
J2: ADDR_BUS; PinHeader_2x08_P2.54mm_Vertical
J3: POWER; PinHeader_2x05_P2.54mm_Vertical
J4: PORT1; PinHeader_2x08_P2.54mm_Vertical
J5: PORT2; PinHeader_2x08_P2.54mm_Vertical
J6: LAN POWER; PinHeader_2x03_P2.54mm_Vertical
J7: LAN CONTROL; PinHeader_2x06_P2.54mm_Vertical
J8: Barrel_Jack_Switch; BarrelJack_Horizontal
MH1, MH2, MH3, MH4, MH5: MountingHole_3.2mm_M3
Q1: 32.768kHz; Crystal_DS26_D2.0mm_L6.0mm_Horizontal
R1: 430; R_0603_1608Metric_Pad0.98x0.95mm_HandSolder
R2, R3: 3.3K; R_0603_1608Metric_Pad0.98x0.95mm_HandSolder
R4: 3.3k; R_0603_1608Metric_Pad0.98x0.95mm_HandSolder
SW1: RESET; SW_PUSH_6mm
SW2: BOOTSTRAP; SW_PUSH_6mm
U1: MC68EZ328; TQFP-100_14x14mm_P0.5mm
U2: MT4LC4M16R6; TSOP-II-50_21x10.16mm_P0.8mm
U3, U4: AM29LV033; TSOP-I-40_18.4x10mm_P0.5mm
U5, U6, U7, U8: 74LCX245; TSSOP-20_4.4x6.5mm_P0.65mm
U9: 74LCX00; TSSOP-14_4.4x5mm_P0.65mm
U10: DS1306; TSSOP-20_4.4x6.5mm_P0.65mm

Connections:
/A1: U1.83, U2.19, U3.21, U4.21, U5.3
/A2: U1.84, U2.20, U3.20, U4.20, U5.4
/A3: U1.85, U2.21, U3.19, U4.19, U5.5
/A4: U1.86, U2.22, U3.18, U4.18, U5.6
/A5: U1.88, U2.23, U3.17, U4.17, U5.7
/A6: U1.89, U2.24, U3.16, U4.16, U5.8
/A7: U1.90, U2.27, U3.15, U4.15, U5.9
/A8: U1.91, U2.28, U3.14, U4.14, U6.2
/A9: U1.92, U2.29, U3.8, U4.8, U6.3
/A10: U1.93, U2.30, U3.7, U4.7, U6.4
/A11: U1.94, U2.31, U3.36, U4.36, U6.5
/A12: U1.95, U2.32, U3.6, U4.6, U6.6
/A13: U1.96, U2.33, U3.5, U4.5, U6.7
/A14: U1.98, U3.4, U4.4, U6.8
/A15: U1.99, U3.3, U4.3, U6.9
/A16: U1.100, U3.2, U4.2
/A17: U1.1, U3.1, U4.1
/A18: U1.2, U3.40, U4.40
/A19: U1.3, U3.13, U4.13
/A20: U1.4, U3.37, U4.37
/A21: U1.5, U3.38, U4.38
/A22: U1.6, U3.29, U4.29
/AB1: J2.1, J7.1, U5.17
/AB2: J2.2, J7.2, U5.16
/AB3: J2.3, J7.3, U5.15
/AB4: J2.4, J7.4, U5.14
/AB5: J2.5, U5.13
/AB6: J2.6, U5.12
/AB7: J2.7, U5.11
/AB8: J2.8, U6.18
/AB9: J2.9, U6.17
/AB10: J2.10, U6.16
/AB11: J2.11, U6.15
/AB12: J2.12, U6.14
/AB13: J2.13, U6.13
/AB14: J2.14, U6.12
/AB15: J2.15, U6.11
/CLOCK: U1.23, U10.18
/D0: U1.75, U2.41, U3.25, U8.9
/D1: U1.74, U2.42, U3.26, U8.8
/D2: U1.73, U2.43, U3.27, U8.7
/D3: U1.72, U2.44, U3.28, U8.6
/D4: U1.71, U2.46, U3.32, U8.5
/D5: U1.70, U2.47, U3.33, U8.4
/D6: U1.69, U2.48, U3.34, U8.3
/D7: U1.68, U2.49, U3.35, U8.2
/D8: U1.66, U2.10, U4.25, U7.9
/D9: U1.65, U2.9, U4.26, U7.8
/D10: U1.64, U2.8, U4.27, U7.7
/D11: U1.63, U2.7, U4.28, U7.6
/D12: U1.62, U2.5, U4.32, U7.5
/D13: U1.61, U2.4, U4.33, U7.4
/D14: U1.60, U2.3, U4.34, U7.3
/D15: U1.59, U2.2, U4.35, U7.2
/DB0: J1.1, U8.11
/DB1: J1.2, U8.12
/DB2: J1.3, U8.13
/DB3: J1.4, U8.14
/DB4: J1.5, U8.15
/DB5: J1.6, U8.16
/DB6: J1.7, U8.17
/DB7: J1.8, U8.18
/DB8: J1.9, U7.11
/DB9: J1.10, U7.12
/DB10: J1.11, U7.13
/DB11: J1.12, U7.14
/DB12: J1.13, U7.15
/DB13: J1.14, U7.16
/DB14: J1.15, U7.17
/DB15: J1.16, U7.18
/LACD: J5.16, U1.38
/LCLK: J5.13, U1.39
/LCON: J5.15, J7.11, U1.37
/LD0: J5.7, U1.46
/LD1: J5.10, U1.45
/LD2: J5.9, U1.44
/LD3: J5.12, U1.43
/LFLM: J5.11, U1.42
/LLP: J5.14, U1.41
/PD0: J4.2, U1.36
/PD1: J4.1, U1.35
/PD2: J4.4, U1.34
/PD3: J4.3, U1.33
/PD4: J4.6, U1.32
/PD5: J4.5, U1.30
/PD6: J4.8, U1.29
/PD7: J4.7, U1.28
/PWM0: J5.8, U1.47
/RXD: J4.14, U1.13
/SCLK: J4.13, U1.11, U10.14
/SRXD: J4.16, U1.10, U10.16
/STXD: J4.15, U1.9, U10.15
/TIME: U1.54, U10.12
/TXD: J4.11, U1.14
/~BDM: J4.10, R2.2, SW2.1, U1.21
/~CAS0: U1.51, U2.37
/~CAS1: U1.50, U2.38
/~CSA0: U1.57, U3.22, U4.22
/~CTS: J4.9, U1.16
/~DWE: U1.12, U2.13
/~EXTRN: J5.5, J7.9, U1.55, U7.19, U8.19
/~IRQ5: J7.6, U1.27
/~LWE: J5.6, U1.81, U3.9
/~PRSET: U1.77, U9.2, U9.11
/~RAS0: U1.53, U2.14
/~RD: J5.4, J7.8, U1.79, U2.36, U3.24, U4.24, U7.1, U8.1
/~RESET: J5.1, J7.5, U3.10, U4.10, U9.6
/~RTS: J4.12, U1.15
/~SRSET: U1.56, U9.1
/~UWE: J5.3, J7.7, U1.80, U4.9
/~XRSET: C3.1, D1.2, J5.2, R4.2, SW1.1, U9.9, U9.10
GND: BT1.2, C1.2, C3.2, C4.2, C5.2, C6.2, C7.2, C8.2, C9.2, C10.2, C11.2, C12.2, C13.2, C14.2, C15.2, C16.2, C18.2, J3.7, J3.8, J3.9, J3.10, J6.5, J6.6, J8.2, J8.3, SW1.2, SW2.2, U1.8, U1.22, U1.31, U1.49, U1.67, U1.87, U2.26, U2.39, U2.45, U2.50, U3.23, U3.39, U4.23, U4.39, U5.10, U5.19, U6.10, U6.19, U7.10, U8.10, U9.7, U10.1, U10.10
unnamed: BT1.1, U10.2
unnamed: C4.1, C18.1, R1.2, U1.25
unnamed: Q1.1, U10.3
unnamed: Q1.2, U10.5
unnamed: R3.2, U1.76
unnamed: U9.3, U9.4, U9.5
unnamed: U9.8, U9.12, U9.13
VDD: C1.1, C5.1, C6.1, C7.1, C8.1, C9.1, C10.1, C11.1, C12.1, C13.1, C14.1, C15.1, C16.1, D1.1, J3.1, J3.2, J3.3, J3.4, J6.1, J6.2, J8.1, R1.1, R2.1, R3.1, R4.1, U1.17, U1.40, U1.58, U1.78, U1.97, U2.1, U2.6, U2.12, U2.25, U3.30, U3.31, U4.30, U4.31, U5.1, U5.2, U5.20, U6.1, U6.20, U7.20, U8.20, U9.14, U10.11, U10.17, U10.20

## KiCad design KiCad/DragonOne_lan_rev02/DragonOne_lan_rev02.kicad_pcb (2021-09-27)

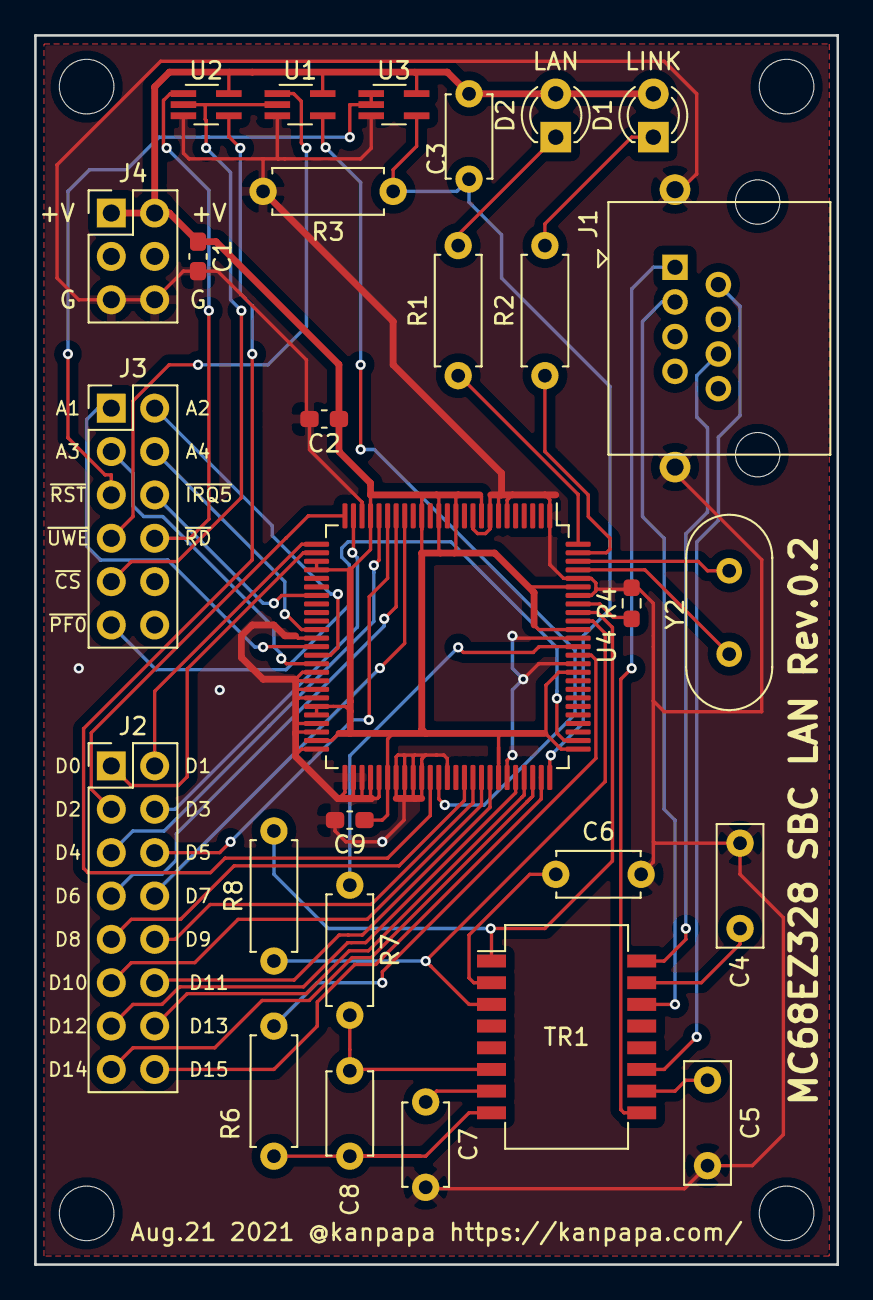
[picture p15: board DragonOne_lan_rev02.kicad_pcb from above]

Board: 2 copper layers, 47.0 x 72.0 mm, 32 parts (0 on the bottom side), 52 nets.

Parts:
C1, C2, C9: 0.1uF; C_0603_1608Metric_Pad1.08x0.95mm_HandSolder
C3, C6, C7: 0.1uF; C_Disc_D4.7mm_W2.5mm_P5.00mm
C4: 4700pF/1kV; C_Disc_D7.0mm_W2.5mm_P5.00mm
C5: 4700pF/1KV; C_Disc_D7.0mm_W2.5mm_P5.00mm
C8: 560pF; C_Disc_D4.7mm_W2.5mm_P5.00mm
D1: LINK LED; LED_D3.0mm
D2: LAN LED; LED_D3.0mm
J1: 8P8C_Shielded; RJ45_Akizuki_7810-8P8C
J2: DATA_BUS; PinHeader_2x08_P2.54mm_Vertical
J3: CTRL_BUS; PinHeader_2x06_P2.54mm_Vertical
J4: PWR; PinHeader_2x03_P2.54mm_Vertical
MH1, MH2, MH3, MH4: MountingHole_3.2mm_M3
R1, R2: 560; R_Axial_DIN0207_L6.3mm_D2.5mm_P7.62mm_Horizontal
R3: 100K; R_Axial_DIN0207_L6.3mm_D2.5mm_P7.62mm_Horizontal
R4: 4.99K 1%; R_0603_1608Metric_Pad0.98x0.95mm_HandSolder
R6, R7: 8.2 1%; R_Axial_DIN0207_L6.3mm_D2.5mm_P7.62mm_Horizontal
R8: 100, 1%; R_Axial_DIN0207_L6.3mm_D2.5mm_P7.62mm_Horizontal
TR1: E2023EL; Transformer_Ethernet_Bourns_PT61017PEL
U1, U2: TC7S32FU; SOT-353_SC-70-5_Handsoldering
U3: TC7SH00FU; SOT-353_SC-70-5_Handsoldering
U4: CS8900A-CQ3Z; TQFP-100_14x14mm_P0.5mm
Y2: 20MHz; Crystal_HC49-4H_Vertical

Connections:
/AB1: J3.1, U4.38
/AB2: J3.2, U4.39
/AB3: J3.3, U4.40
/AB4: J3.4, U4.36
/DB0: J2.1, U4.27
/DB1: J2.2, U4.26
/DB2: J2.3, U4.25
/DB3: J2.4, U4.24
/DB4: J2.5, U4.21
/DB5: J2.6, U4.20
/DB6: J2.7, U4.19
/DB7: J2.8, U4.18
/DB8: J2.9, U4.65
/DB9: J2.10, U4.66
/DB10: J2.11, U4.67
/DB11: J2.12, U4.68
/DB12: J2.13, U4.71
/DB13: J2.14, U4.72
/DB14: J2.15, U4.73
/DB15: J2.16, U4.74
/PF0: J3.11, U4.77
/RD+: J1.3, TR1.14
/RD-: J1.6, TR1.16
/RXD+: R8.1, TR1.3, U4.91
/RXD-: R8.2, TR1.1, U4.92
/TD+: J1.1, TR1.9
/TD-: J1.2, TR1.11
/TXD+: C8.1, R6.2, TR1.8
/TXD-: C8.2, R7.2, TR1.6
/~CSB0: J3.9, U1.2, U2.2
/~IRQ5: J3.6, U4.32
/~RD: J3.8, U2.1
/~RESET: J3.5, U3.1, U3.2
/~UWE: J3.7, U1.1
GND: C1.2, C2.2, C4.2, C5.2, C6.2, C7.2, C9.2, J1.SH, J4.5, J4.6, R3.2, R4.2, U1.3, U2.3, U3.3, U4.1, U4.6, U4.7, U4.8, U4.10, U4.23, U4.37, U4.41, U4.42, U4.43, U4.44, U4.47, U4.48, U4.50, U4.51, U4.52, U4.53, U4.54, U4.55, U4.57, U4.58, U4.59, U4.60, U4.63, U4.70, U4.86, U4.89, U4.94, U4.96
unnamed: C3.2, R3.1, U3.4, U4.75
unnamed: C4.1, TR1.15
unnamed: C5.1, TR1.10
unnamed: C6.1, TR1.2
unnamed: C7.1, TR1.7
unnamed: D1.1, R2.2
unnamed: D2.1, R1.2
unnamed: R1.1, U4.100
unnamed: R2.1, U4.99
unnamed: R4.1, U4.93
unnamed: R6.1, U4.87
unnamed: R7.1, U4.88
unnamed: U1.4, U4.62
unnamed: U2.4, U4.61
unnamed: U4.97, Y2.2
unnamed: U4.98, Y2.1
VCC: C1.1, C2.1, C3.1, C9.1, D1.2, D2.2, J4.1, J4.2, U1.5, U2.5, U3.5, U4.9, U4.12, U4.14, U4.16, U4.22, U4.28, U4.29, U4.45, U4.46, U4.49, U4.56, U4.69, U4.76, U4.85, U4.90, U4.95

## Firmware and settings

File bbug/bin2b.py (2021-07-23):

#
# Binary to B-record convert program 0.1
# for MC68EZ328
# date: 2021/07/23
# Kazuhiro Ouchi @kanpapa
#
# Usage:
#        bin2b.py <Binary filename>
#

import sys

# Get Binary file name
sfilename = sys.argv[1]

# Open binary file
f = open(sfilename, 'rb')

# Kernel at x instead of 0
pc = 0x00200000
linecounter = 0
eof = False

# command buffer
command = ''

while not eof: 
    b = f.read(1)
    if not b:
        eof = True
    else:
        command = command + b.hex().upper()

    linecounter += 1
    if linecounter == 0x15 or eof == True:
        print(format(pc, '08X'), end='')
        print(format(linecounter, '02X'), end='')
        print(command)
        pc += linecounter
        linecounter = 0
        command = ''

f.close();

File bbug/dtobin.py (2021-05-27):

#
# m68k-monitor dump record to binary program 0.1
# for MC68EZ328
# date: 2021/05/27
# Kazuhiro Ouchi @kanpapa
#
# Usage:
#        dtobin.py <DUMP record filename>
#

import sys
import struct

# Get Dump record file name
sfilename = sys.argv[1]

# Open sfile
fin = open(sfilename, 'r')

# Open Output binary file
outfilename = sfilename+".bin"
fout = open(outfilename, 'wb')

datalist = fin.readlines()
for data in datalist:
    cols = 0
    for coldata in data.split():
        cols += 1
        if len(coldata) == 2:
            a = int(coldata, 16);
            fout.write(struct.pack("B", a))
            if cols > 16:
                break;

fout.close()
fin.close()

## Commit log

2021-04-24 Added schematic
2021-04-25 Updated schematic
2021-05-21 Added ucsimm sample boot log
2021-07-25 説明を追加
2021-07-25 m68k toolchainのリポジトリを変更
2021-08-06 Added schematics for LAN board
2021-08-22 Added DS1306 Sample program
2021-08-22 Updated SPI sample program for DS1306
2021-09-05 Added LAN board Rev0.2
    [MC68EZ328_SBC_LAN_Rev0_2_BOM.tsv]
2021-09-20 Added KiCad files
    [DragonOne_cpu_rev03-B_Cu.gbl, DragonOne_cpu_rev03-B_Mask.gbs, DragonOne_cpu_rev03-B_SilkS.gbo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]
2021-09-20 Added BOM for MC68EZ328 SBC Rev0.3
2021-09-20 Added schematic for DragonOne SBC Rev. 0.3
2024-02-24 Added CSV file
    [MC68EZ328_SBC_Rev0_3_BOM.csv]
2024-02-24 Changed tsv to csv and file name.
    [MC68EZ328_SBC_CPU_Rev0_3_BOM.csv, MC68EZ328_SBC_LAN_Rev0_2_BOM.csv, MC68EZ328_SBC_LAN_Rev0_2_BOM.tsv]
2024-02-24 Update PCB images

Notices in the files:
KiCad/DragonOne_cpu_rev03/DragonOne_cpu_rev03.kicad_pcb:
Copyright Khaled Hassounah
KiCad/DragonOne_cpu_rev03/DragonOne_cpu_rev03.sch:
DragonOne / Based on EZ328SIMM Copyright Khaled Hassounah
